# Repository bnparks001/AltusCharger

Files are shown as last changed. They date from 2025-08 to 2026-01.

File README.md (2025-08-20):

<div align="center">
  <h1>Altus Charger</h1>
  6 channel output charger for AltusMetrum batteries. 
  
  ## Status
  Boards have arrived and passed testing great!
  <div>
    <h3><em>Assembled Board:</em></h3>
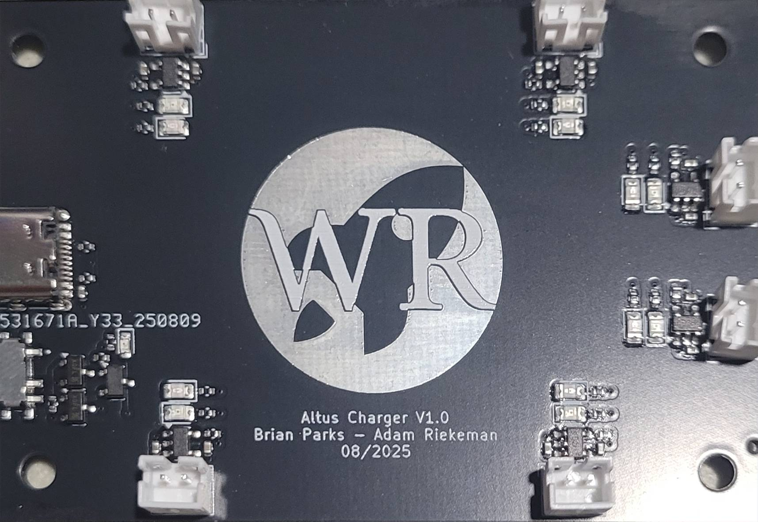
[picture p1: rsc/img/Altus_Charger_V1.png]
Altus Charger Board
    
  </div>
  
  ## Hardware
  This project is designed to support charging of 6 Altus Metrum batteries over a 5V 2A USB-C connection using the same battery charging circuit as the Telemega. Therefore, the RProg resistor selection was set to 3.3k to charge each battery at ~300mA. For context, the Telemega integrated charger is configured to charge at ~342mA. This results in ~13% slower charging per battery. However, with the benefit of charging multiple batteries at once this quickly makes up the difference.
  This project also includes a switch to turn off the LED indicators for overnight charging. 
  
  ## Schematic
  <h3><em>Root Schematic:</em></h3>
  <p>The root level schematic shows the overall blocking of the hardware design.</p>
  Root Schematic<br>
      
  ## PCB Design
  <div>
    <h3><em>3D Render:</em></h3>
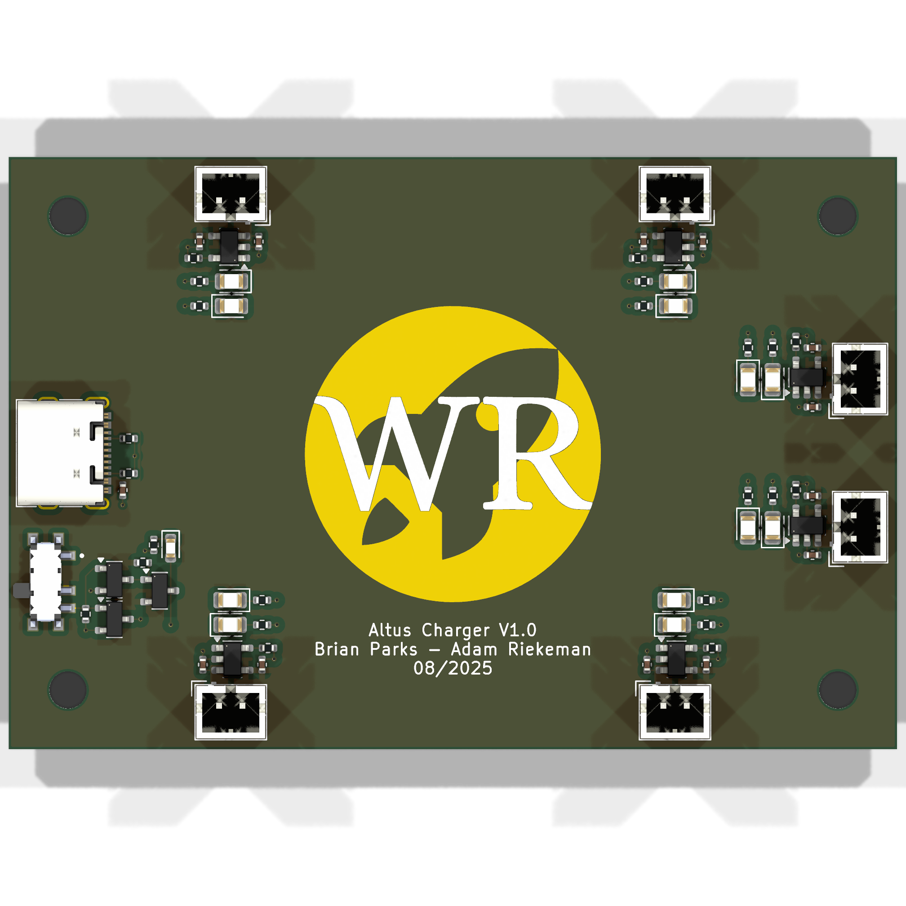
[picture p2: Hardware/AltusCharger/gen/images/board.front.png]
    
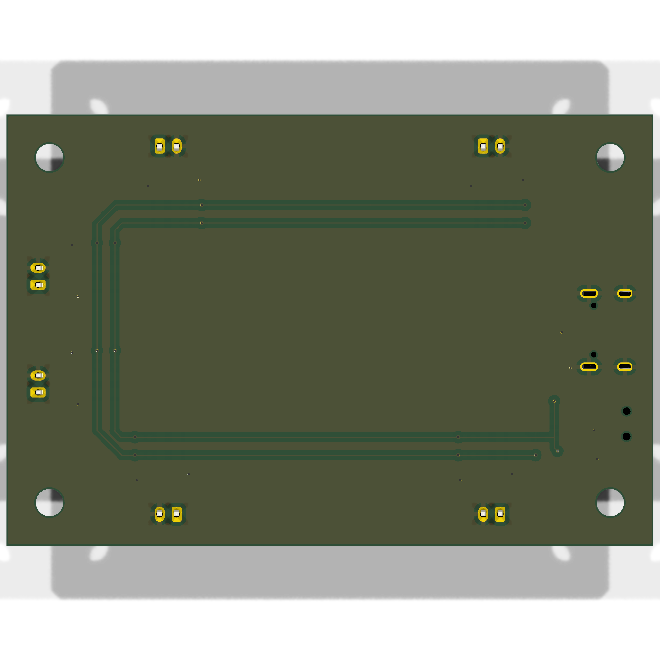
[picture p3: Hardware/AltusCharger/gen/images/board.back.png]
    
  </div>
  
  <div>
    <h3><em>PCB Artwork:</em></h3>
    Front
    Back<br>
  </div>
</div>

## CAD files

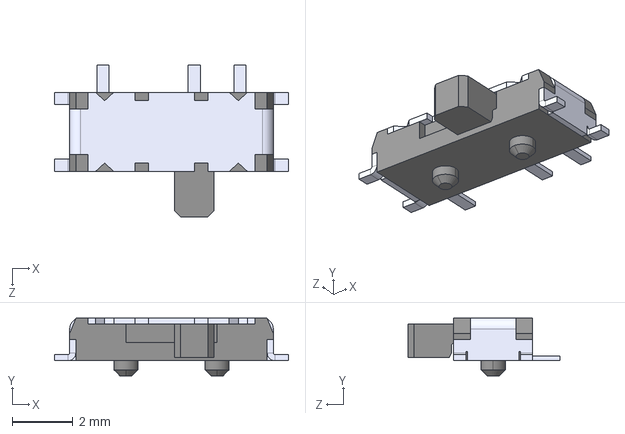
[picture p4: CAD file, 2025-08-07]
Hardware/AltusCharger-Lib/AltusCharger Part Models/SSSS811101.step
7.70 x 1.90 x 5.00 mm

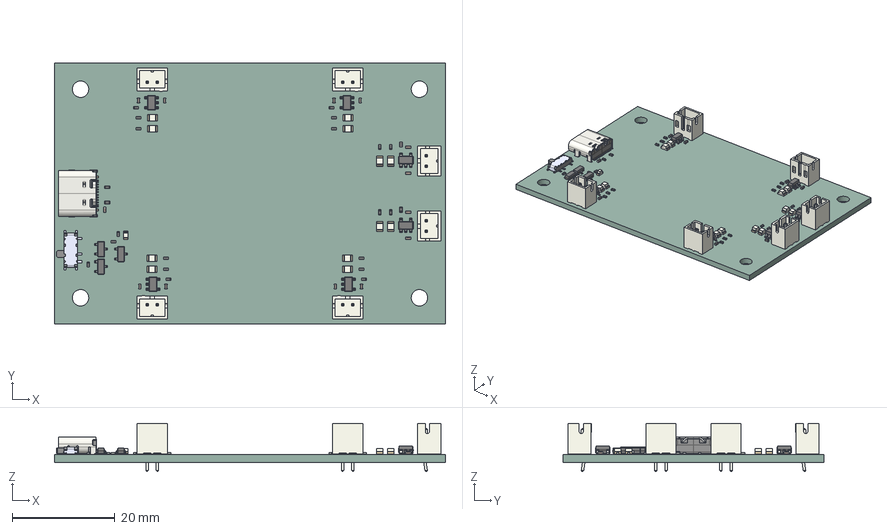
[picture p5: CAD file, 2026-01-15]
Hardware/AltusCharger/gen/3d/pcb_model.step
76.2 x 50.8 x 9.40 mm
LED_0805_2012Metric x 12
R_0402_1005Metric x 23
LED_0603_1608Metric
C_0402_1005Metric x 13
JST_PH_B2B-PH-K_1x02_P2.00mm_Vertical x 6
SOT-23-5 x 6
SSSS811101
SOT-23 x 3
USB_C_Receptacle_GCT_USB4105-xx-A_16P_TopMnt_Horizontal
AltusCharger_PCB

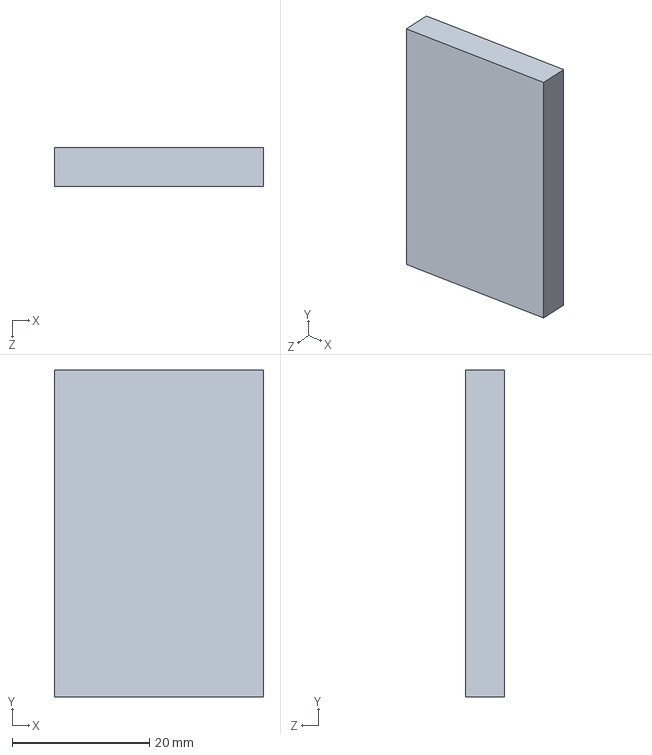
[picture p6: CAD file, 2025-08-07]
Physical/850mAhAltusBattery.SLDPRT
30.5 x 47.6 x 5.72 mm

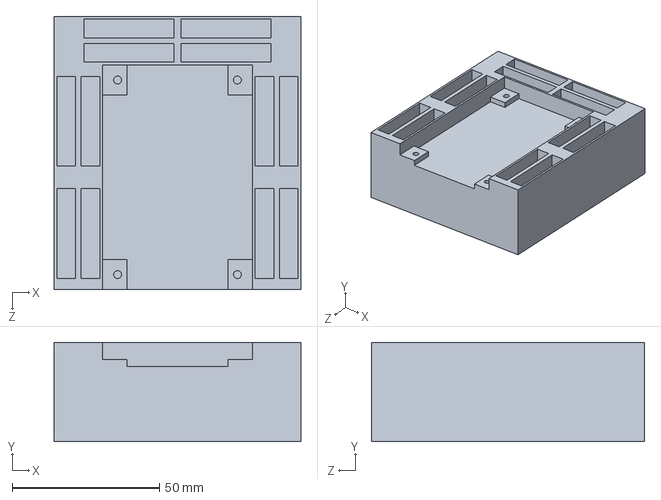
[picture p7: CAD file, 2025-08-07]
Physical/BatteryHolder.SLDPRT
83.8 x 33.7 x 92.7 mm

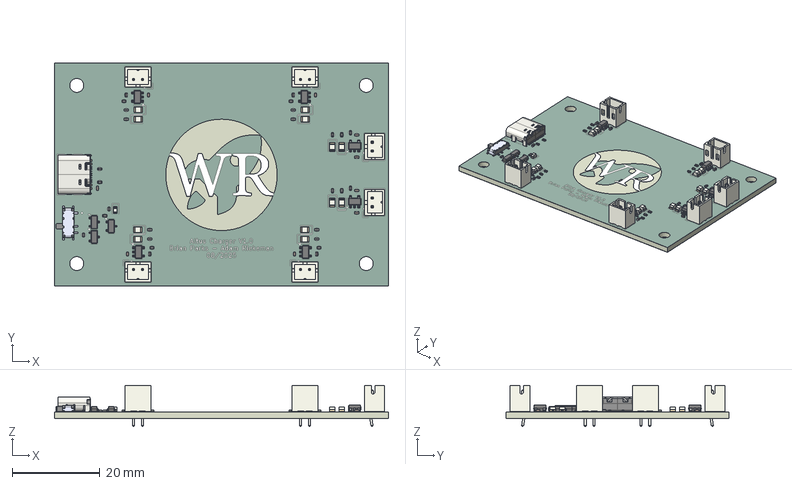
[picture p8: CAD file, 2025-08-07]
Physical/AltusChargerV1.step
76.2 x 50.8 x 9.40 mm
LED_0805_2012Metric x 12
R_0402_1005Metric x 23
LED_0603_1608Metric
C_0402_1005Metric x 13
JST_PH_B2B-PH-K_1x02_P2.00mm_Vertical x 6
SOT-23-5 x 6
kicad_embedded_D42D50230B76A4E84A28EE23A2FC8E44
SOT-23 x 3
USB_C_Receptacle_GCT_USB4105-xx-A_16P_TopMnt_Horizontal
AltusCharger_silkscreen
AltusCharger_soldermask
AltusCharger_PCB

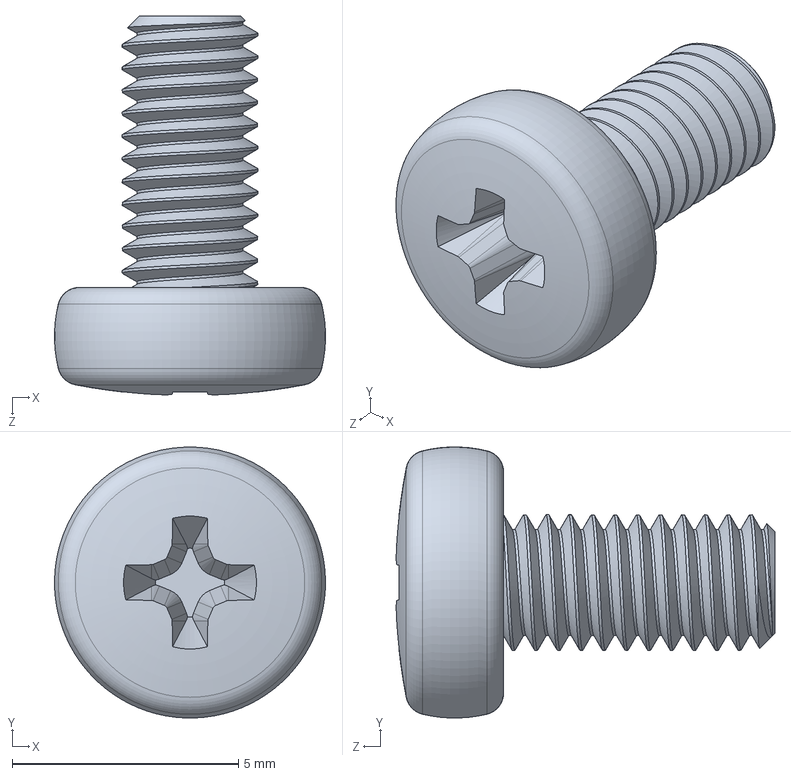
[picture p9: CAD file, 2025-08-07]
Physical/M3X6Screw_92005A116.SLDPRT
6.00 x 5.99 x 8.38 mm

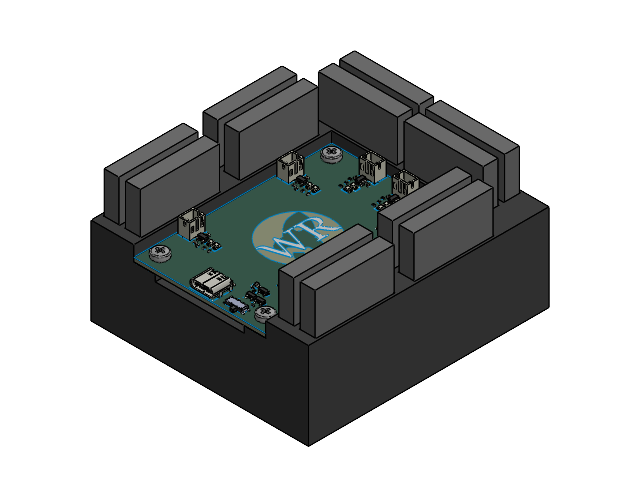
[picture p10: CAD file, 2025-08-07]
Physical/Charging Assembly.SLDASM
BatteryHolder
LED_0805_2012Metric_1.step x 12
R_0402_1005Metric_1.step x 23
LED_0603_1608Metric_1.step
C_0402_1005Metric_1.step x 13
JST_PH_B2B-PH-K_1x02_P2.00mm_Vertical_1.step x 6
SOT-23-5_1.step x 6
kicad_embedded_D42D50230B76A4E84A28EE23A2FC8E44_1.step
SOT-23_1.step x 3
USB_C_Receptacle_GCT_USB4105-xx-A_16P_TopMnt_Horizontal_1.step
AltusCharger_silkscreen.step
AltusCharger_soldermask.step
AltusCharger_PCB_1.step
M3X6Screw_92005A116 x 4
850mAhAltusBattery x 12

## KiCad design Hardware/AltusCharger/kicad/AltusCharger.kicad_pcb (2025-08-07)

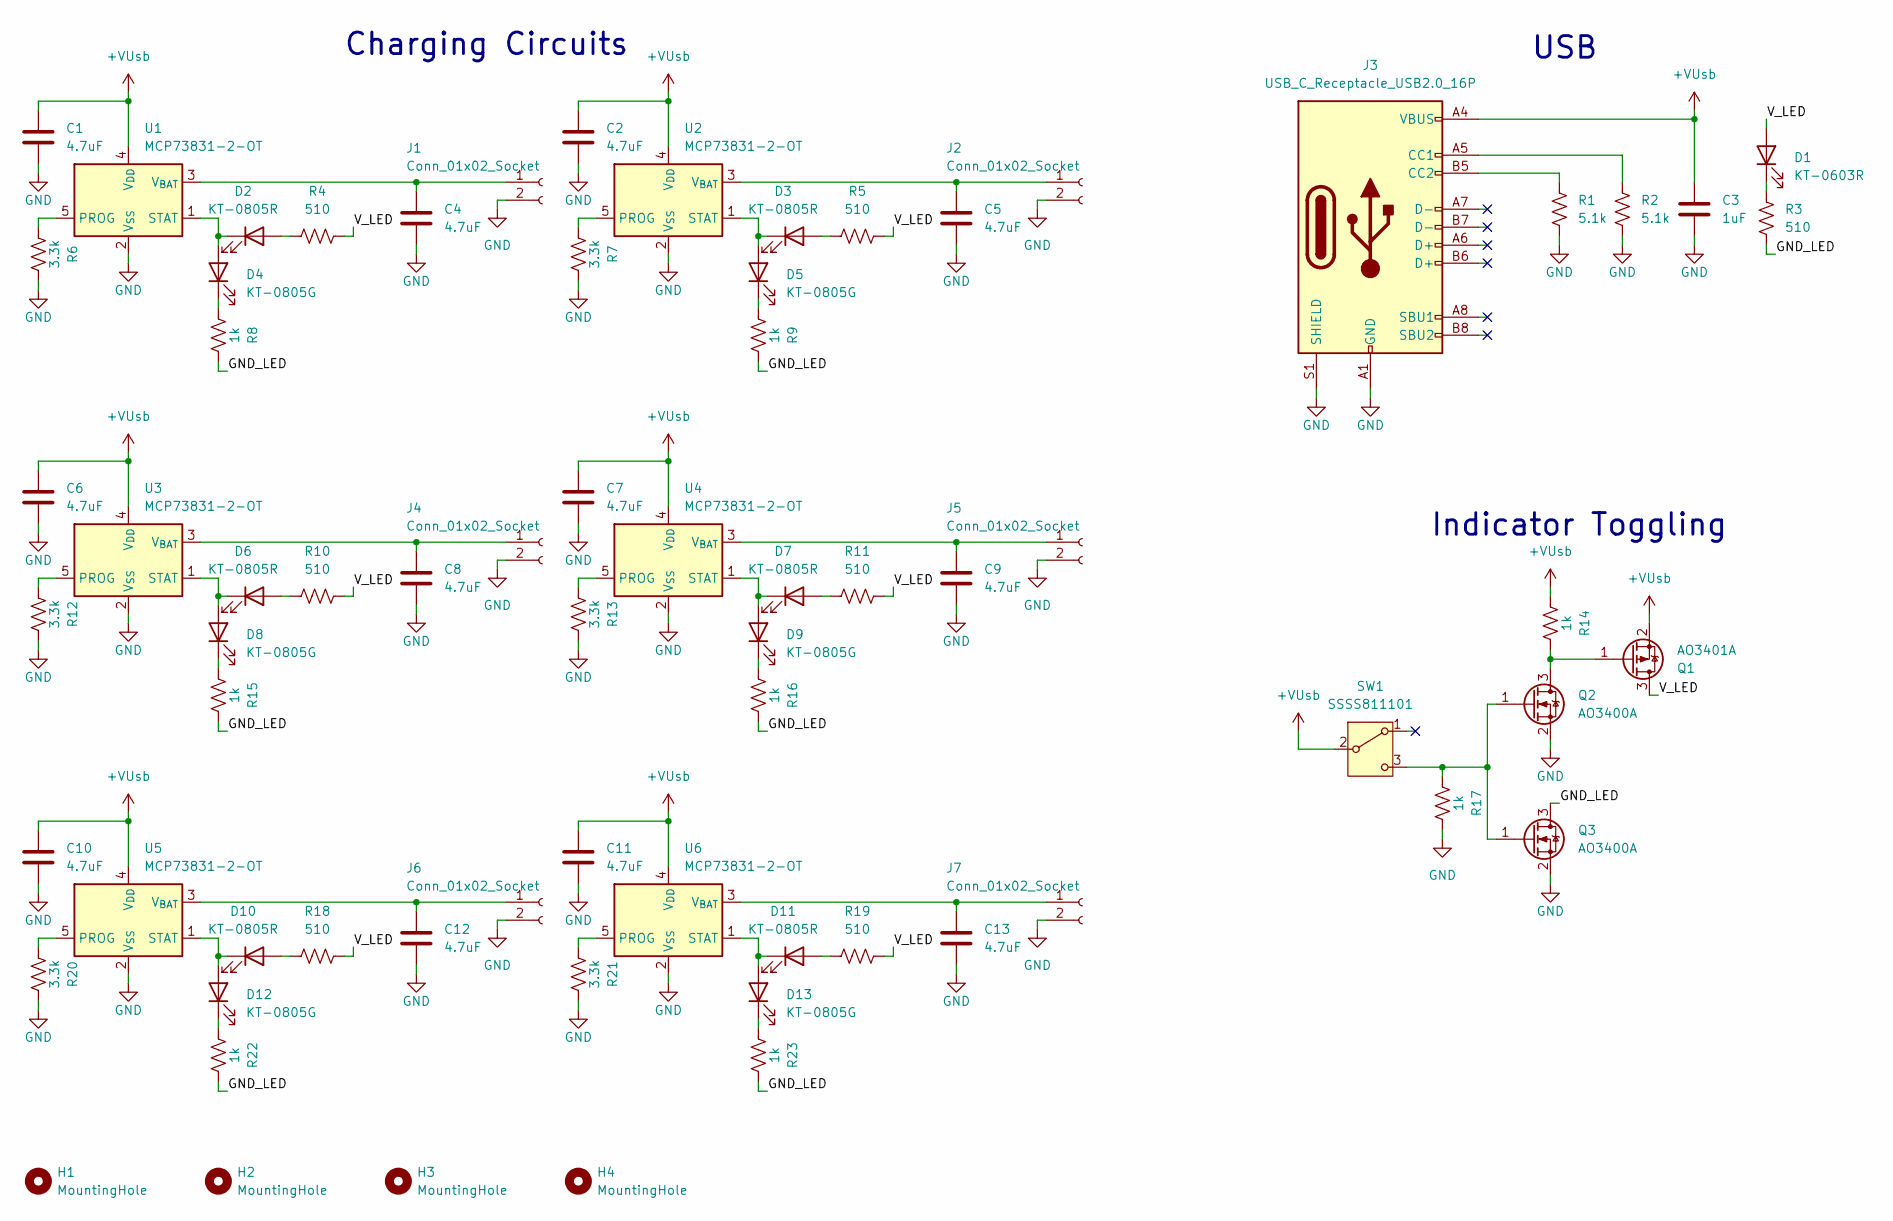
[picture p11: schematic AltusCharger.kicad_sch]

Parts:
C1, C2, C4, C5, C6, C7, C8, C9, C10, C11, C12, C13: 4.7uF; C_0402_1005Metric; JLCPCB Part # C23733
C3: 1uF; C_0402_1005Metric; JLCPCB Part # C52923
D1: KT-0603R; LED_0603_1608Metric; JLCPCB Part # C2286
D2, D3, D6, D7, D10, D11: KT-0805R; LED_0805_2012Metric; JLCPCB Part # C2295
D4, D5, D8, D9, D12, D13: KT-0805G; LED_0805_2012Metric; JLCPCB Part # C2297
H1, H2, H3, H4: MountingHole; MountingHole_3.2mm_M3
J1, J2, J4, J5, J6, J7: Conn_01x02_Socket; JST_PH_B2B-PH-K_1x02_P2.00mm_Vertical; JLCPCB Part # C2319
J3: USB_C_Receptacle_USB2.0_16P; USB_C_Receptacle_G-Switch_GT-USB-7010ASV; JLCPCB Part # C2988369
Q1: AO3401A; SOT-23; JLCPCB Part # C15127
Q2, Q3: AO3400A; SOT-23; JLCPCB Part # C20917
R1, R2: 5.1k; R_0402_1005Metric; JLCPCB Part # C25905
R3, R4, R5, R10, R11, R18, R19: 510; R_0402_1005Metric; JLCPCB Part # C25123
R6, R7, R12, R13, R20, R21: 3.3k; R_0402_1005Metric; JLCPCB Part # C25890
R8, R9, R14, R15, R16, R17, R22, R23: 1k; R_0402_1005Metric; JLCPCB Part # C11702
SW1: SSSS811101; SW_SSSS811101; JLCPCB Part # C109335
U1, U2, U3, U4, U5, U6: MCP73831-2-OT; SOT-23-5; JLCPCB Part # C424093

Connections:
+VUsb: C1.1, C2.1, C3.1, C6.1, C7.1, C10.1, C11.1, J3.A4 (VBUS), J3.A9 (VBUS), J3.B4 (VBUS), J3.B9 (VBUS), Q1.2 (S), R14.1, SW1.2 (B), U1.4 (V_{DD}), U2.4 (V_{DD}), U3.4 (V_{DD}), U4.4 (V_{DD}), U5.4 (V_{DD}), U6.4 (V_{DD})
/GND_LED: Q3.3 (D), R3.2, R8.2, R9.2, R15.2, R16.2, R22.2, R23.2
/V_LED: D1.2 (A), Q1.3 (D), R4.2, R5.2, R10.2, R11.2, R18.2, R19.2
GND: C1.2, C2.2, C3.2, C4.2, C5.2, C6.2, C7.2, C8.2, C9.2, C10.2, C11.2, C12.2, C13.2, J1.2, J2.2, J3.A1 (GND), J3.A12 (GND), J3.B1 (GND), J3.B12 (GND), J3.S1 (SHIELD), J4.2, J5.2, J6.2, J7.2, Q2.2 (S), Q3.2 (S), R1.2, R2.2, R6.2, R7.2, R12.2, R13.2, R17.2, R20.2, R21.2, U1.2 (V_{SS}), U2.2 (V_{SS}), U3.2 (V_{SS}), U4.2 (V_{SS}), U5.2 (V_{SS}), U6.2 (V_{SS})
unnamed: D1.1 (K), R3.1
unnamed: D2.2 (A), R4.1
unnamed: D2.1 (K), D4.2 (A), U1.1 (STAT)
unnamed: D3.2 (A), R5.1
unnamed: D3.1 (K), D5.2 (A), U2.1 (STAT)
unnamed: D4.1 (K), R8.1
unnamed: D5.1 (K), R9.1
unnamed: D6.2 (A), R10.1
unnamed: D6.1 (K), D8.2 (A), U3.1 (STAT)
unnamed: D7.2 (A), R11.1
unnamed: D7.1 (K), D9.2 (A), U4.1 (STAT)
unnamed: D8.1 (K), R15.1
unnamed: D9.1 (K), R16.1
unnamed: D10.2 (A), R18.1
unnamed: D10.1 (K), D12.2 (A), U5.1 (STAT)
unnamed: D11.2 (A), R19.1
unnamed: D11.1 (K), D13.2 (A), U6.1 (STAT)
unnamed: D12.1 (K), R22.1
unnamed: D13.1 (K), R23.1
unnamed: C4.1, J1.1, U1.3 (V_{BAT})
unnamed: C5.1, J2.1, U2.3 (V_{BAT})
unnamed: J3.A5 (CC1), R2.1
unnamed: J3.B5 (CC2), R1.1
unnamed: C8.1, J4.1, U3.3 (V_{BAT})
unnamed: C9.1, J5.1, U4.3 (V_{BAT})
unnamed: C12.1, J6.1, U5.3 (V_{BAT})
unnamed: C13.1, J7.1, U6.3 (V_{BAT})
unnamed: Q1.1 (G), Q2.3 (D), R14.2
unnamed: Q2.1 (G), Q3.1 (G), R17.1, SW1.3 (C)
unnamed: R6.1, U1.5 (PROG)
unnamed: R7.1, U2.5 (PROG)
unnamed: R12.1, U3.5 (PROG)
unnamed: R13.1, U4.5 (PROG)
unnamed: R20.1, U5.5 (PROG)
unnamed: R21.1, U6.5 (PROG)

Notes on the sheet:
USB
Charging Circuits
Indicator Toggling

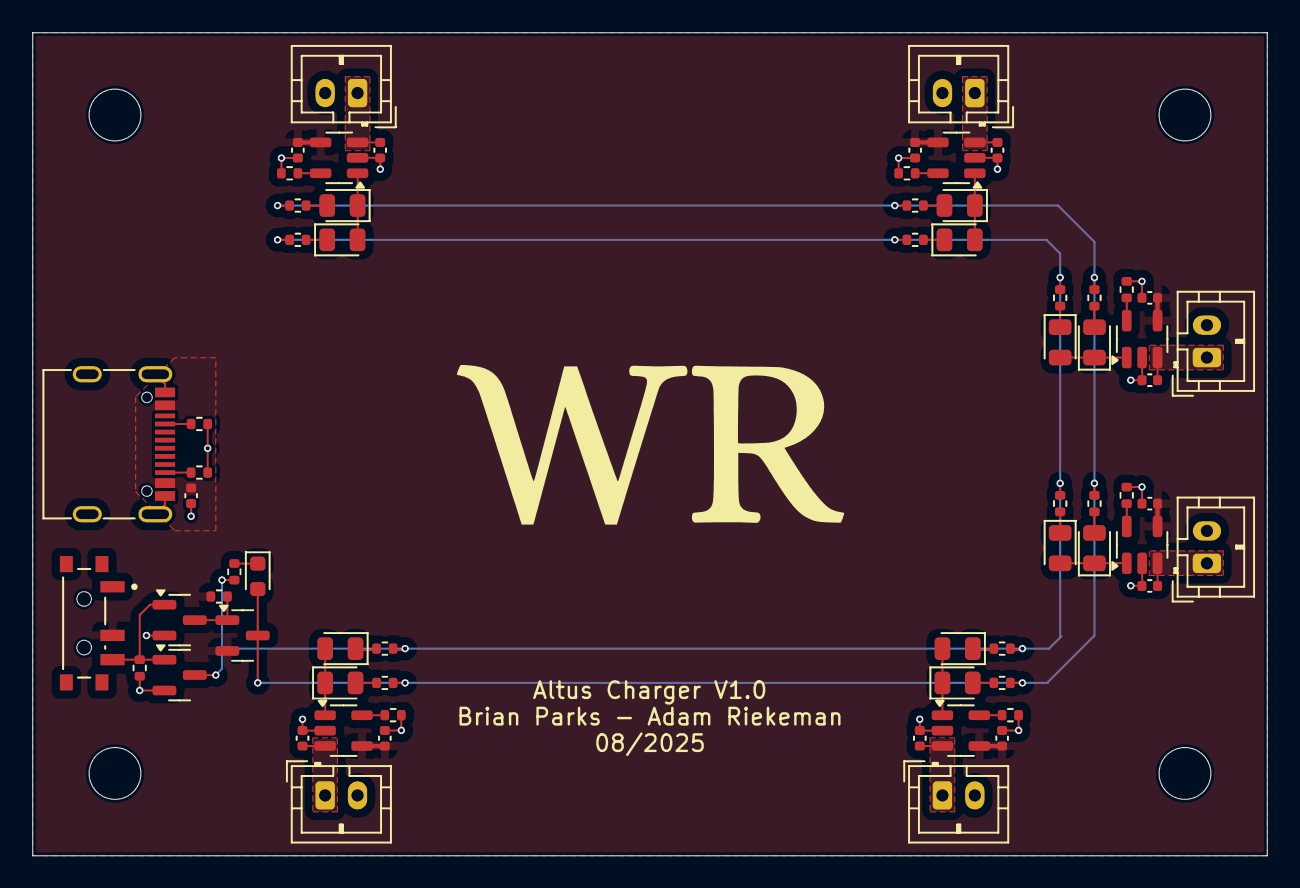
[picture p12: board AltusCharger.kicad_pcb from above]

Board: 2 copper layers, 76.2 x 50.8 mm, 70 parts (0 on the bottom side), 39 nets.

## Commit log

2025-08-07 Did schematic
    [AltusCharger.kicad_pcb, AltusCharger.kicad_sch, SSSS811101.step]
2025-08-07 Mounting holes for schematic
    [AltusCharger.kicad_sch]
2025-08-07 Altus Charger V1.0
    [AltusCharger.kicad_pcb, AltusCharger.kicad_sch]
2025-08-07 Update autogen files
    [pcb_model.step]
2025-08-07 Altus Charger changes to gen fab files
    [AltusCharger.kicad_pcb, AltusCharger.kicad_sch]
2025-08-07 Physical battery holder
    [850mAhAltusBattery.SLDPRT, AltusChargerV1.step, BatteryHolder.SLDPRT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]
2026-01-15 Updated to new resource gen and forced regen
    [AltusCharger.kicad_sch]
